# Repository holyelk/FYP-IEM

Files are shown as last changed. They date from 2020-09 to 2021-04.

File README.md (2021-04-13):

# FYP-IEM
Repository for Bryan's IEM FYP

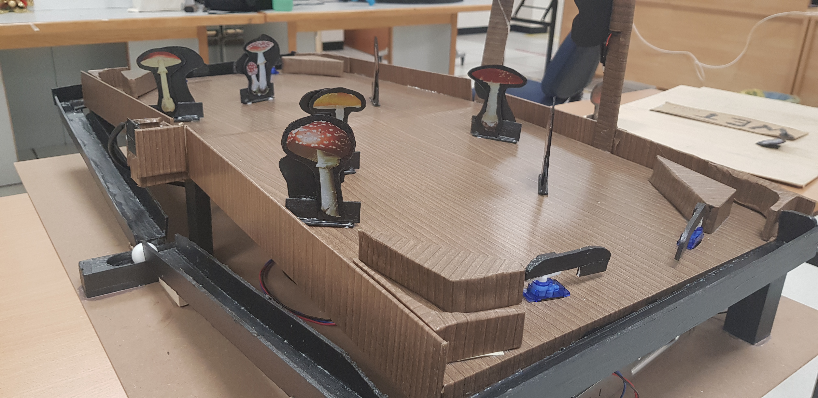
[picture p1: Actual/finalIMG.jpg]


***
### Top level folders will represent what is in them
- Actual
- Research

***
### Actual
Consists of the final code, circuit diagram and the archive of work in progress for this project

### Research
Consists of ideation, planning and other documents before the implementation

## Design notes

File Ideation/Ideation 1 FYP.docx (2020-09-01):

Ideation FYP:

Hiding ducks

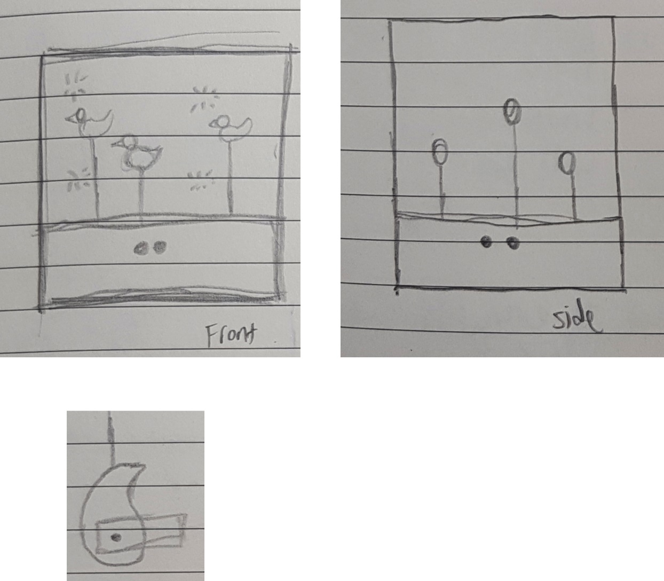
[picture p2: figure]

There will be a box with ducks inside which will be moving. Sensors will be attached to the box and if they sense anyone approaching from within a certain radius, the ducks will hide. This is achieved by making use of a certain shape (shown on the bottom left) to translate circular motion to vertical motion. Possible sensors to use for people sensing is an ultrasonic sensor or a RCWL-0516 Microwave proximity sensor.

The idea behind this is COVID19. As we have seen in the news, without people, nature has been returning to urban areas. Thus this is a replica of humans disappearing and animals returning.

Theremin concept

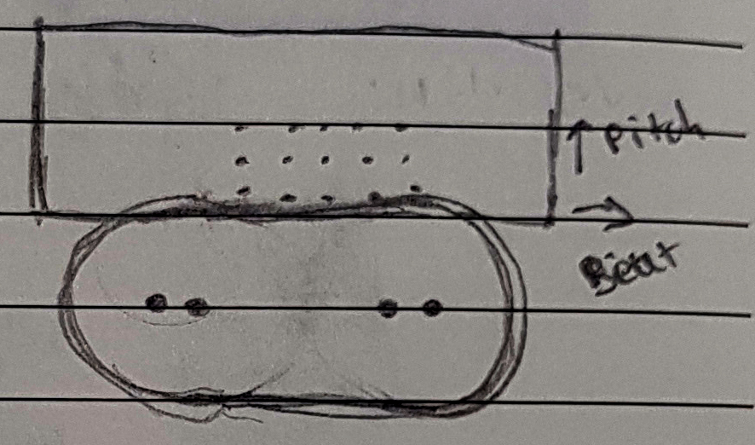
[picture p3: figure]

Using the concept of a theremin where distance and direction of the hand from the antenna is used to measure the pitch and beat of the instrument, I though of using 2 sensors to measure the distance from the display and play the appropriate pitch and beat. An alternative to using distance sensors would be using a camera and having certain poses correspond to some fixed beats/pitches. The beat and pitch would then be displayed on the LED matrix board on the back.

Interactive water display

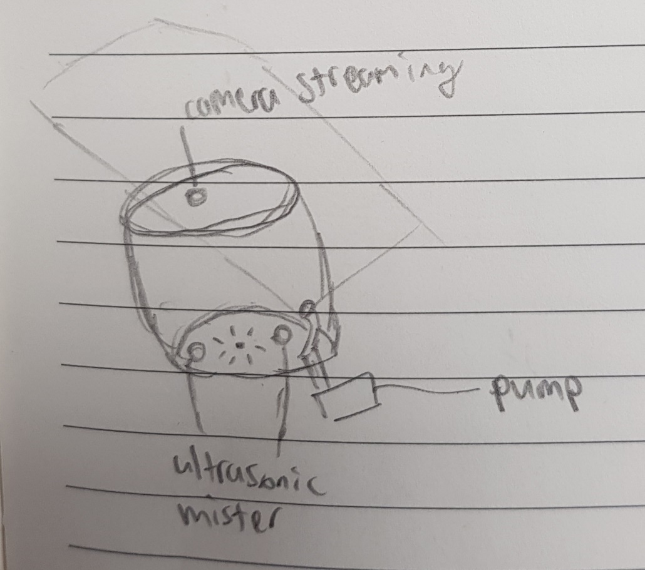
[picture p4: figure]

Through an application online, users will be able to see and interact with this water display. They will be able to see it through a camera the will be streaming from the top and control various actuators through the internet. Various actuators currently thought off are, LED lights, mini water pumps and ultrasonic misters. These 3 would already allow for a wide range of different displays in the water.

I understand that due to the water element, this might be a bit messy.

Real time weather display

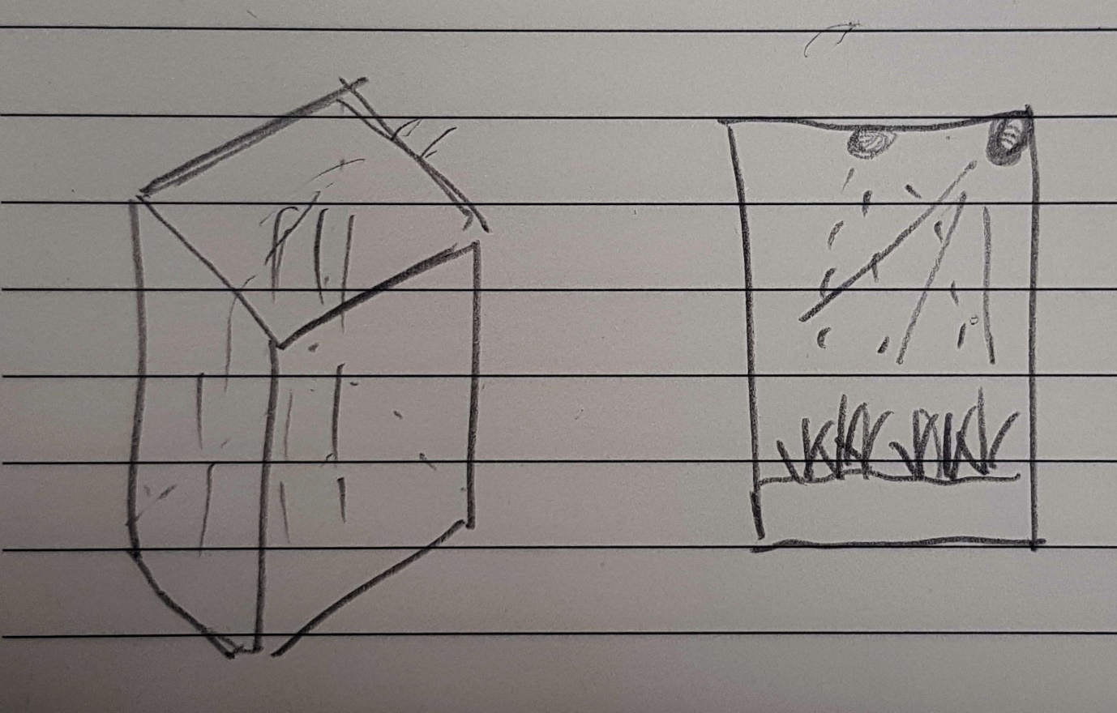
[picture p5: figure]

Using connections to the internet, a semi enclosed tank will replicate the weather we are having in real time. Light for the sun, water sprinkler/pump for rain. As Singapore has only 2 kinds of weather, perhaps temperature can be taken into account as well using a Peltier device.

An alternative would be to have the user control the kind of weather inside the tank via buttons or a webapp.

Magnetic Chaos

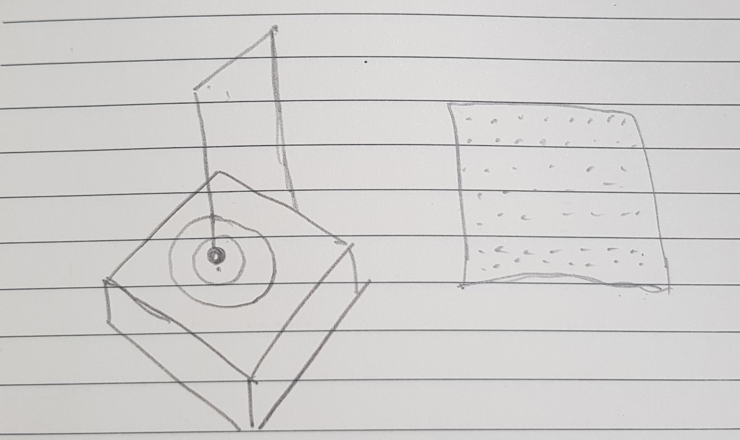
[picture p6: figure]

A magnet will be suspended above the board which is an LED matrix. Beneath the board are hall effect sensors able to sense the magnetic field created by the magnet. Upon a strong magnetic field, IE: The magnet is above the sensor, the corresponding led will light up. This will create a visualization of the chaos theory in action. The LEDs will also be replicated in the digital world by having a screen the represents the LEDs lighting up in real time.

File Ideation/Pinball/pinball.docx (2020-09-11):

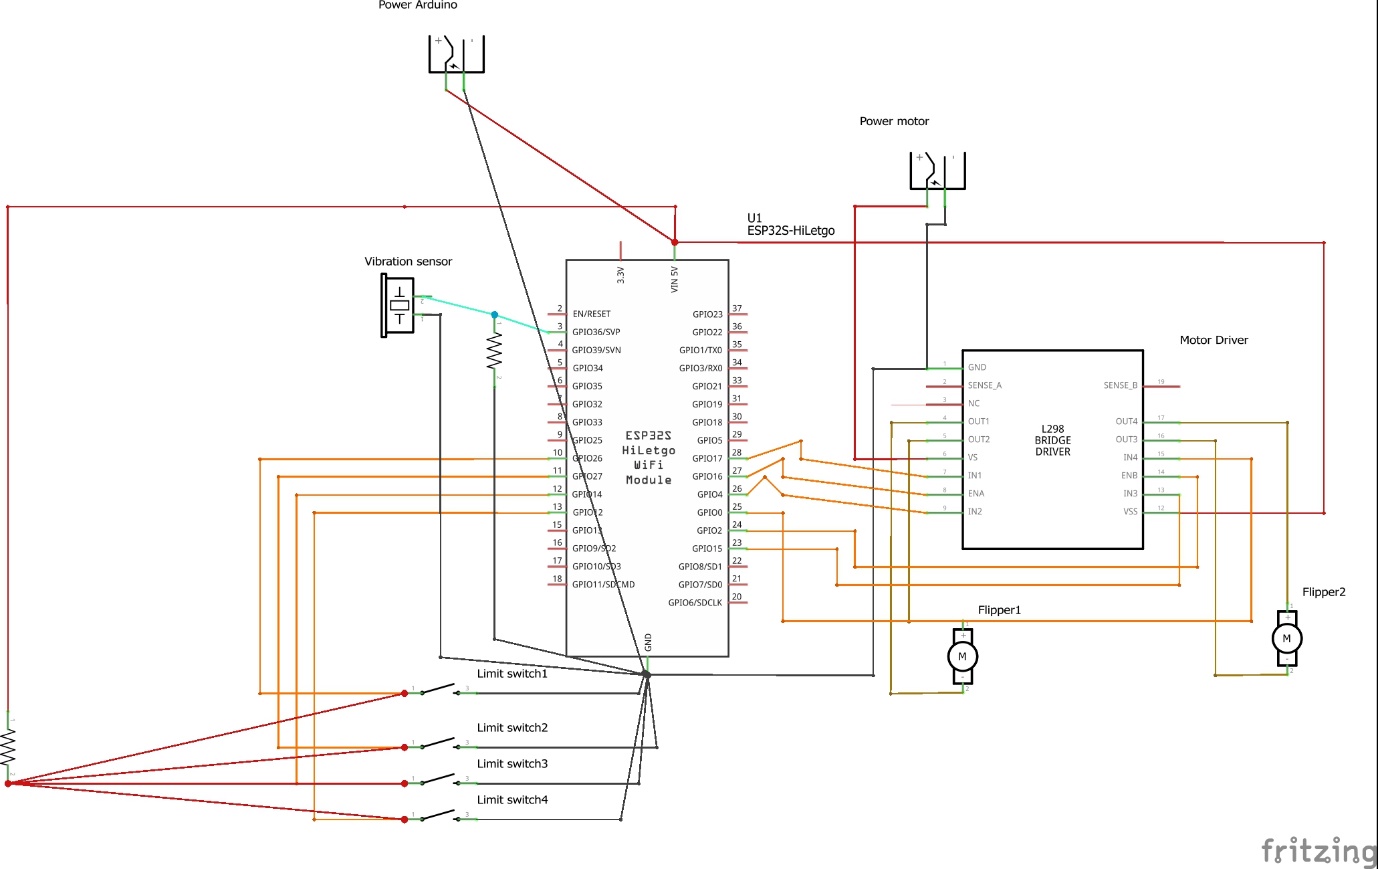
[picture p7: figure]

Parts required:

1x ESP32

2x Power source

2x DC Motors

1x L298 dual H-Bridge Motor Driver

8x Vibration sensors

4x Limit Switches

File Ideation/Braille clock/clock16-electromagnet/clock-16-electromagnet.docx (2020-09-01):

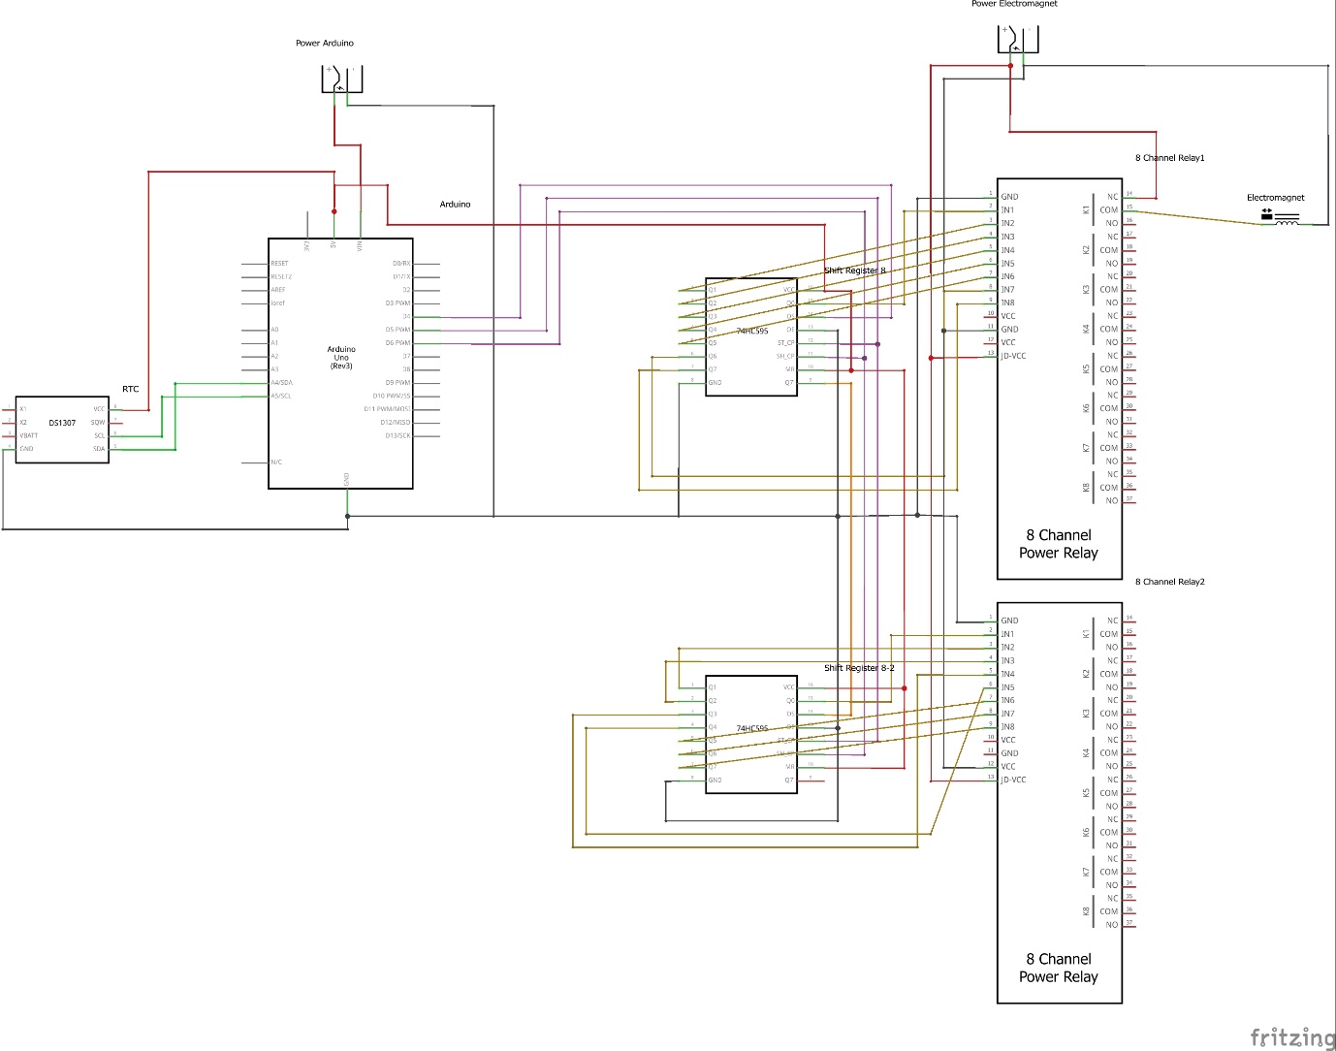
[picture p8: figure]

Parts required:

1x DS1307 (RTC module)

1x Arduino Uno

2x Power source

2x 74HC595 Shift register

2x 8 Channel Power Relay OR 1x 16 Channel Power Relay

16x 12v electromagnet

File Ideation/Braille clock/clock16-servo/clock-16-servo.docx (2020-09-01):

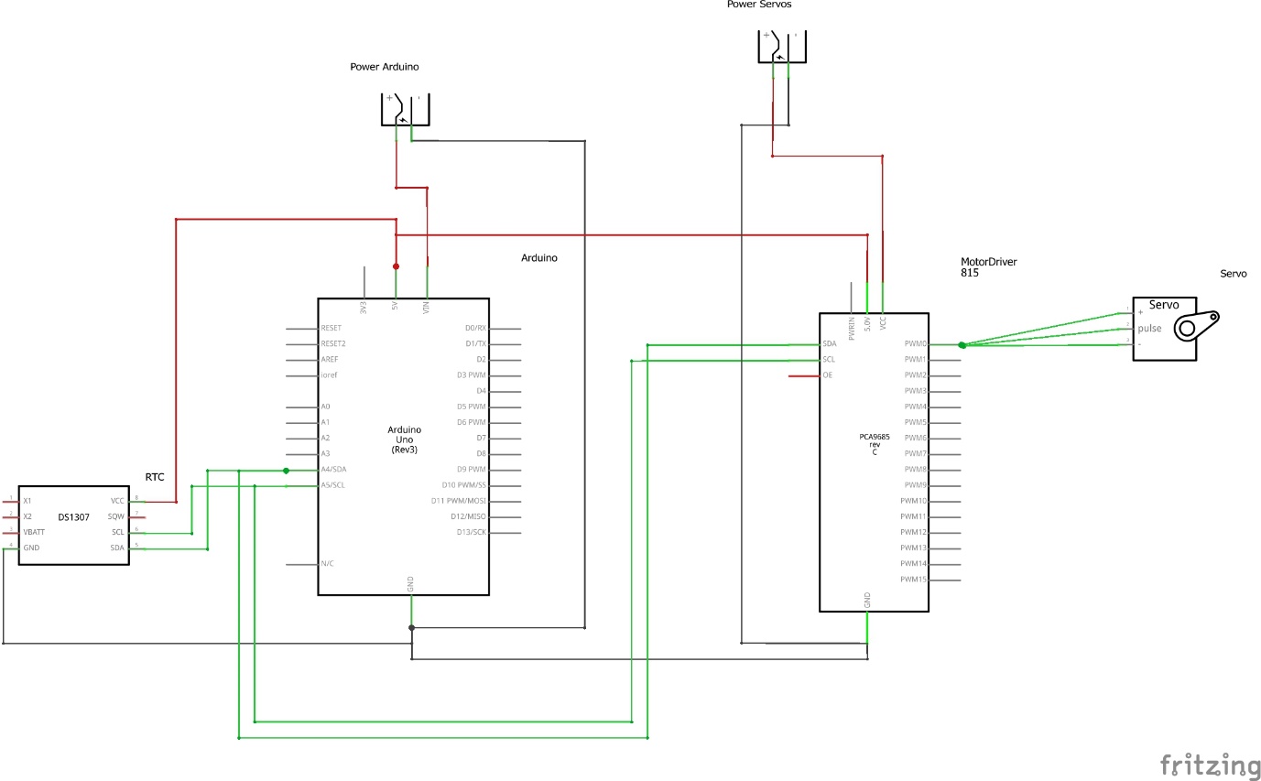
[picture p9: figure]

Parts required:

1x DS1307 (RTC module)

1x Arduino Uno

2x Power source

1x PCA9685 PWM Controller

16x Servos

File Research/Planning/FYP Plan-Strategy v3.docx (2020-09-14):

FYP Plan/Strategy

Background:

The objective of this project is to and construct creative interactive displays using Arduino/Raspberry Pi controller, sensors, actuators, LEDs and speaker, with light, sound, animation and wireless communications. In light of COVID-19 there should also be a virtual display done at the end to allow for a non-physical experience of the project.

The background would be to create an interactive display that is able to be showcased for IEM’s open house displays.

Ideation:

Taking inspiration from both Pong and Pinball, the idea is to create a pinball like game where the user plays against a computer-controlled board to attempt to score. One side will be controlled by the user and the other will be by the computer.

Being pinball like, the goal is defended by the use of 2 flippers and those flippers are used to attack as well. There will be static and dynamic obstacles on the board and in the way of the goals. To ensure users are able to score, the opponent will be programmed in such a way that allows it to sometime miss the ball coming towards it.

The brains of the project will be an Arduino board. The Arduino board will have 3 main functions. Keeping score, controlling the robot opponent and controlling the obstacles. Score will be kept by sensors at the end of the board if it detects the ball then it will add one point. Points will be shown by a 7-segment display. The Arduino will be using IR sensors to see if the ball is coming and use them to know when to activate the flippers. How the flippers will be made will have to be tested. 3 possible paths can be taken. Using a servo motor, using a DC motor with limit switches and using solenoids. Testing will need to be done to see which is sufficient. Lastly, there will be 2 kinds of obstacles. Static and dynamic. Static ones are just there but will have sensors to know if the ball has hit them. If it has been hit, it will light up. Dynamic obstacles are those that will move. These will either be moved by DC motors or servo motors. Having these dynamic obstacles will add more uncertainty and unpredictability to the ball making it more interesting.

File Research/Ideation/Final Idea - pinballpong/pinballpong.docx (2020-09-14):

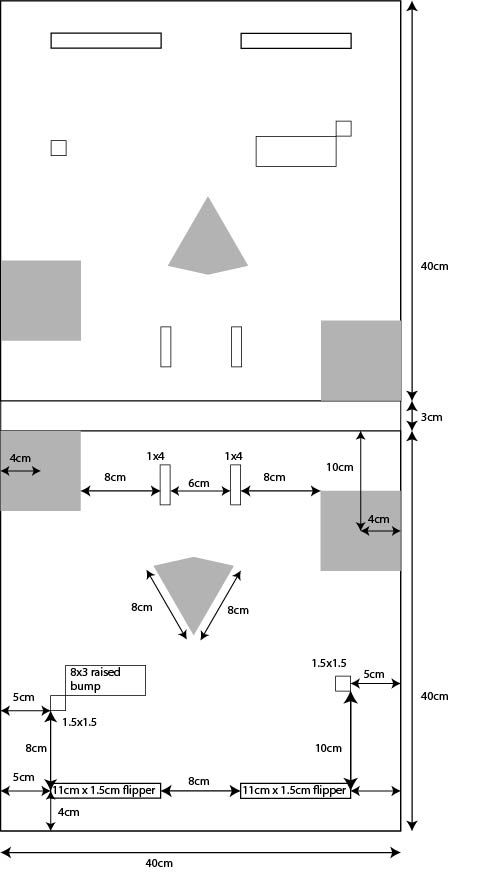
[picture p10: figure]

Figure 1

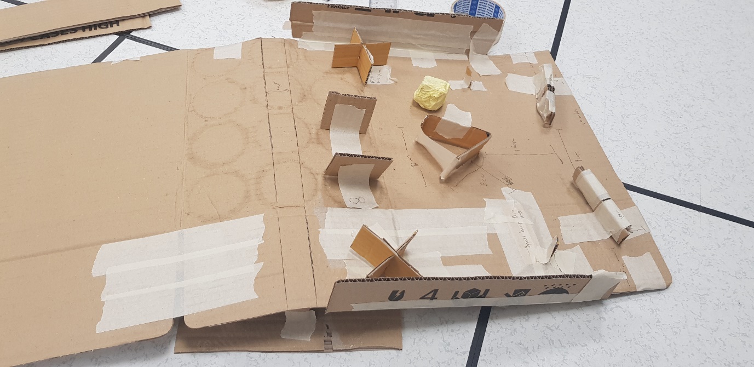
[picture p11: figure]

Figure 2

The entire board will be in the shape of an A-frame slightly tilted toward each side and flat in the middle to allow the ball to roll down on each respective side. The highest point of elevation of the flat middle is 5cm. This allows for a 7-degree incline which is just nice to prevent the ball from rolling too fast. Depending on the ball size selected, the obstacles are subject to change. The current design uses a ping pong ball of standard diameter 4cm as the ball size.

As obstacles are subject to change based on selection of ball, first order of business will be to select the ball and hence determine which type of flippers are strong enough.

Flippers:

If servo:

1x PCA9685 driver ($3)

4x servos ($3 each)

Total - $15

If DC Motor:

2x L298N driver ($2.50 each)

8x Limit Switch ($2.50 for 10)

4x DC Motor ($2 each)

Total - $15.50

If Solenoid:

2x 2N2222A Transistor ($0.50 each)

4x Solenoid ($4 each)

Total - $17

As we can initially see, the best option would be the servo as it is the cheapest. However, the push strength of the servo may not be enough and tests will need to be carried out.

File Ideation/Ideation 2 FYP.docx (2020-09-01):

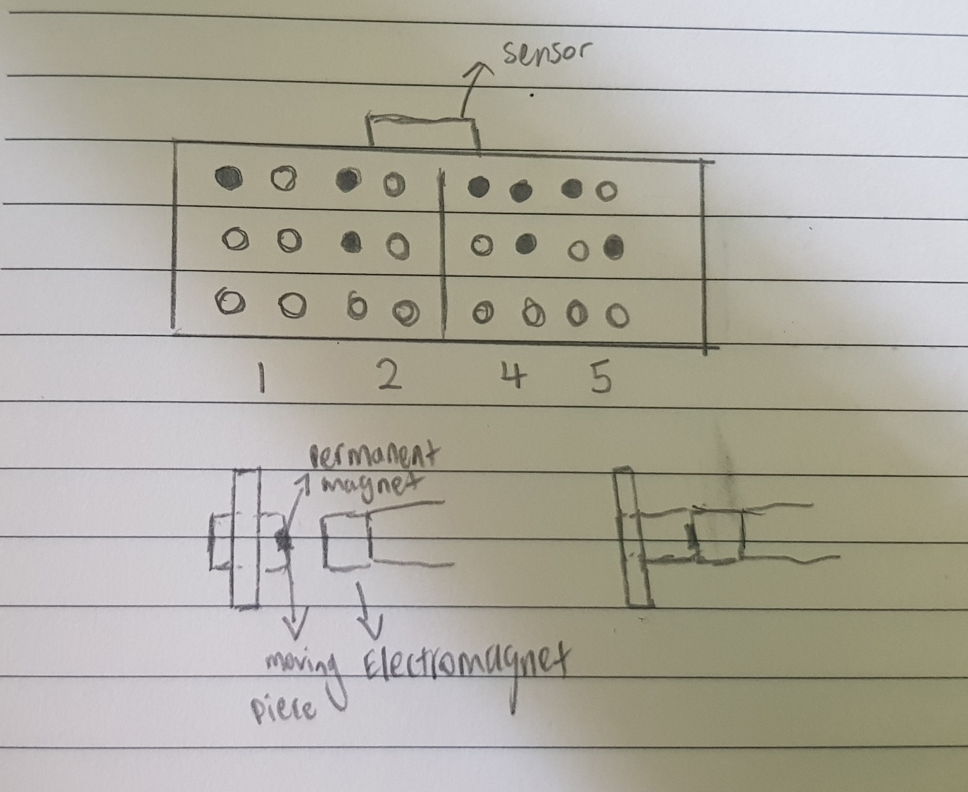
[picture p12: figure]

A braille clock for the visually impaired. How it will work is that there are 24 movable blocks representing the braille numbers. These will move in or out based on the corresponding time. The movement is controlled by an electromagnet that activates and repels based on the correct braille conversion given for the time.

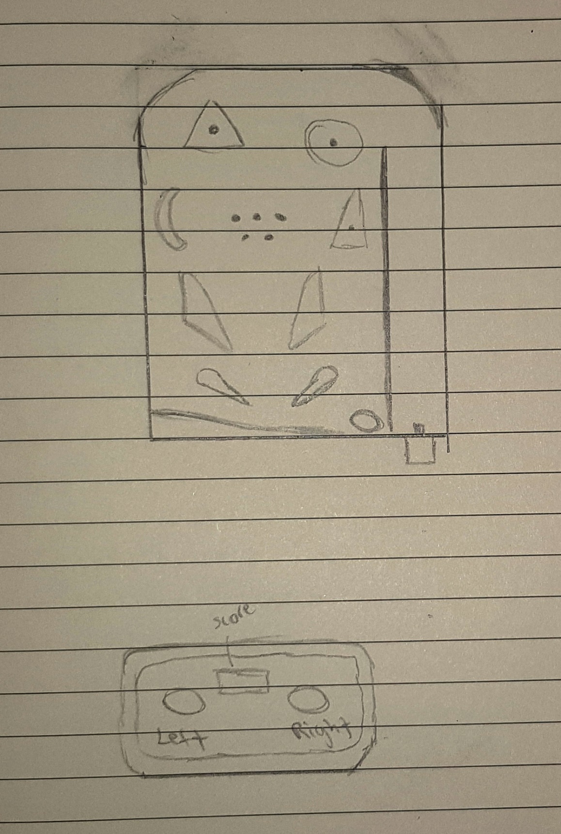
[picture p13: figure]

An IoT Pinball machine. The pinball machine itself is physical. However, the controls are controlled by a smartphone connected to an ESP32 microcontroller.

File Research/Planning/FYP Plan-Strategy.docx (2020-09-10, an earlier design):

FYP Plan/Strategy

Background:

The objective of this project is to and construct creative interactive displays using Arduino/Raspberry Pi controller, sensors, actuators, LEDs and speaker, with light, sound, animation and wireless communications. In light of COVID-19 there should also be a virtual display done at the end to allow for a non-physical experience of the project.

The background would be to create an interactive display that is able to be showcased for IEM’s open house displays.

Ideations:

There are 2 ways that are possible for exploration. The first is an interactive display which depends on light and sound coupled with sensors for activation to create an interactive display. The other would be a tactile interactive display where rather than using light and sound, it uses touch and sound to interact with the audience.

An idea for the first point is to create an IoT pinball machine where the pinball board is physical but the controls are through the user’s mobile phone. This is a bonus during the COVID-19 period as people would not be physically touching the device and only their mobile phones which they already have contact with. If this were to proceed, research would have to be done on the various IoT boards available. Ranging from a Raspberry Pi to a ESP32 controller. Following that, testing and research will be done for how to display the controls on the phone which will have a connection to the various actuators on the pinball machine. Lastly would be the testing of the components and the actual implementation of the device.

An idea for the second point would be since it is to be tactile and sound interaction, the best group of people to cater this towards would be the visually impaired people. The initial idea is to have a clock with numbers represented in braille which would be represented by moving dots. However, further research and interviews would have to be done with visually impaired persons to deem if this idea should move forward. To that end, I have contacted Singapore Association for the Visually Handicapped (SAVH) to seek their advice on this matter. The outcome of this would determine if the FYP would be the IoT pinball machine or the Braille clock.

Refer to TimeSchedule.xlsx for the time schedule

Update 10/9/2020:

A few emails between myself and SAVH and I was given insight into what the visually handicapped people are actually using. I was informed that they currently have 3 kinds of time telling devices being used. The first one that tells the time through sound, the second is through touch of the numbers on a clock face and the last is a braille watch. Since there already exists a braille watch, there is no point in re-inventing the wheel and I will not proceed further on this topic. This means that my focus is now on the IoT pinball machine.

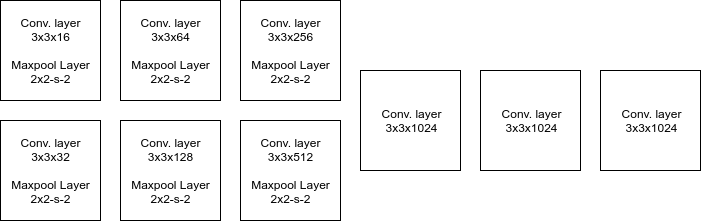
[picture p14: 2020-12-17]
Research/Tinyyolo_architecture.png

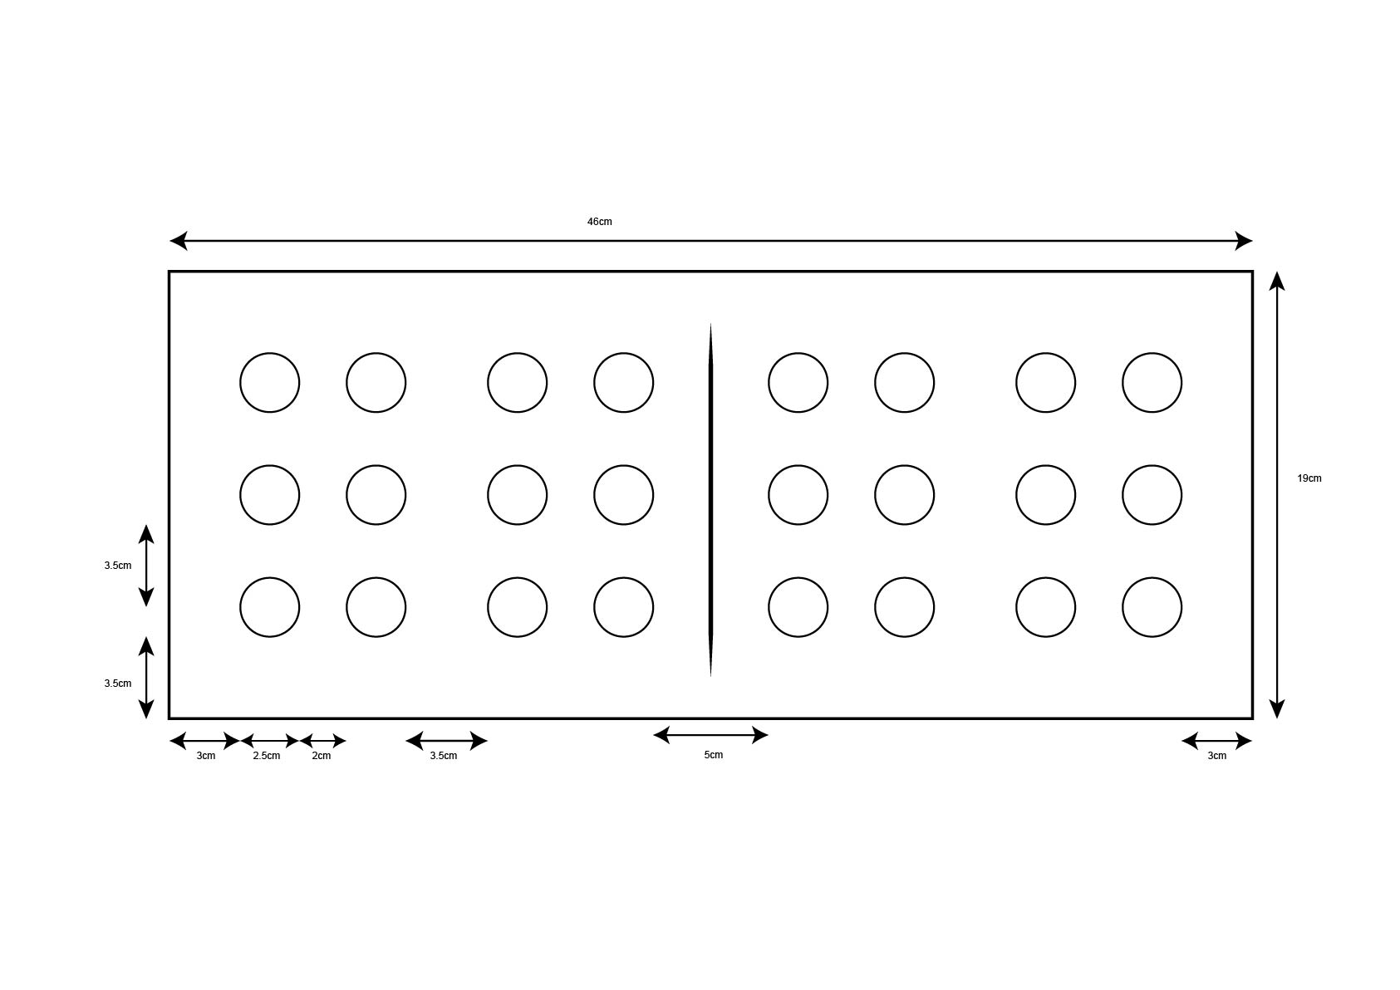
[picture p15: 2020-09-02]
Ideation/Braille clock/Diagram to scale-clock16-01.jpg

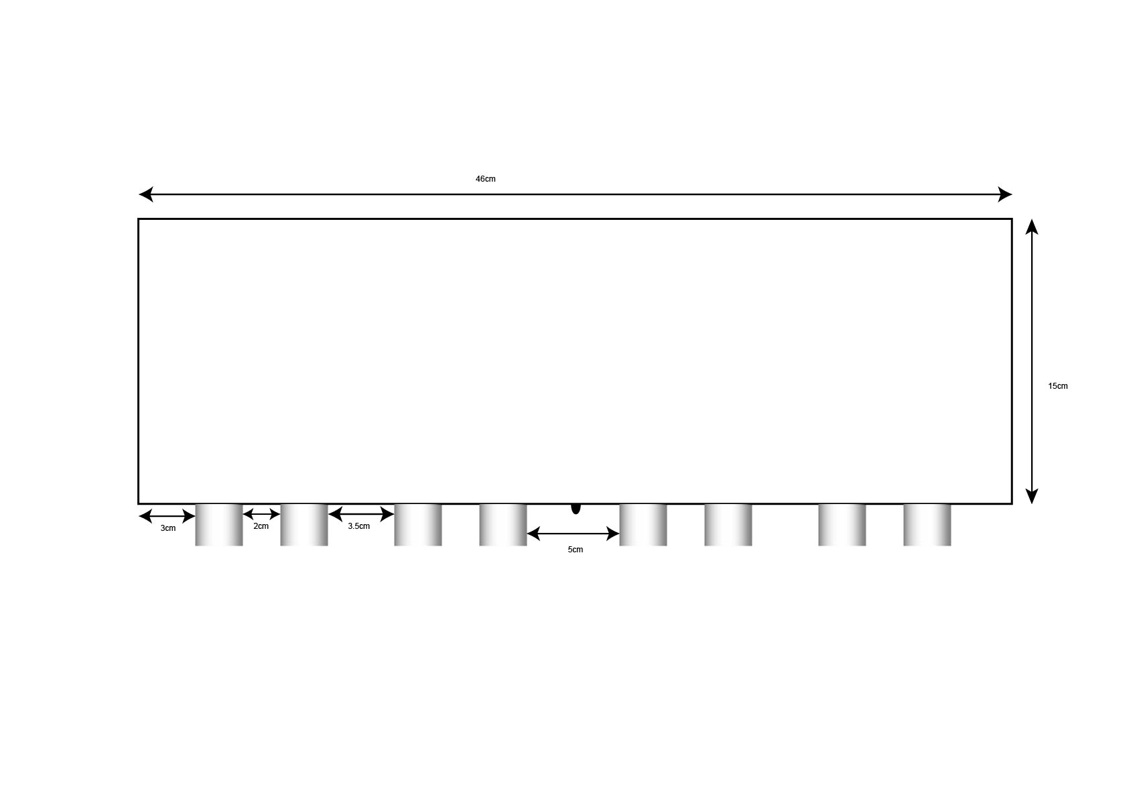
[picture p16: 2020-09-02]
Ideation/Braille clock/Diagram to scale-clock16-02.jpg

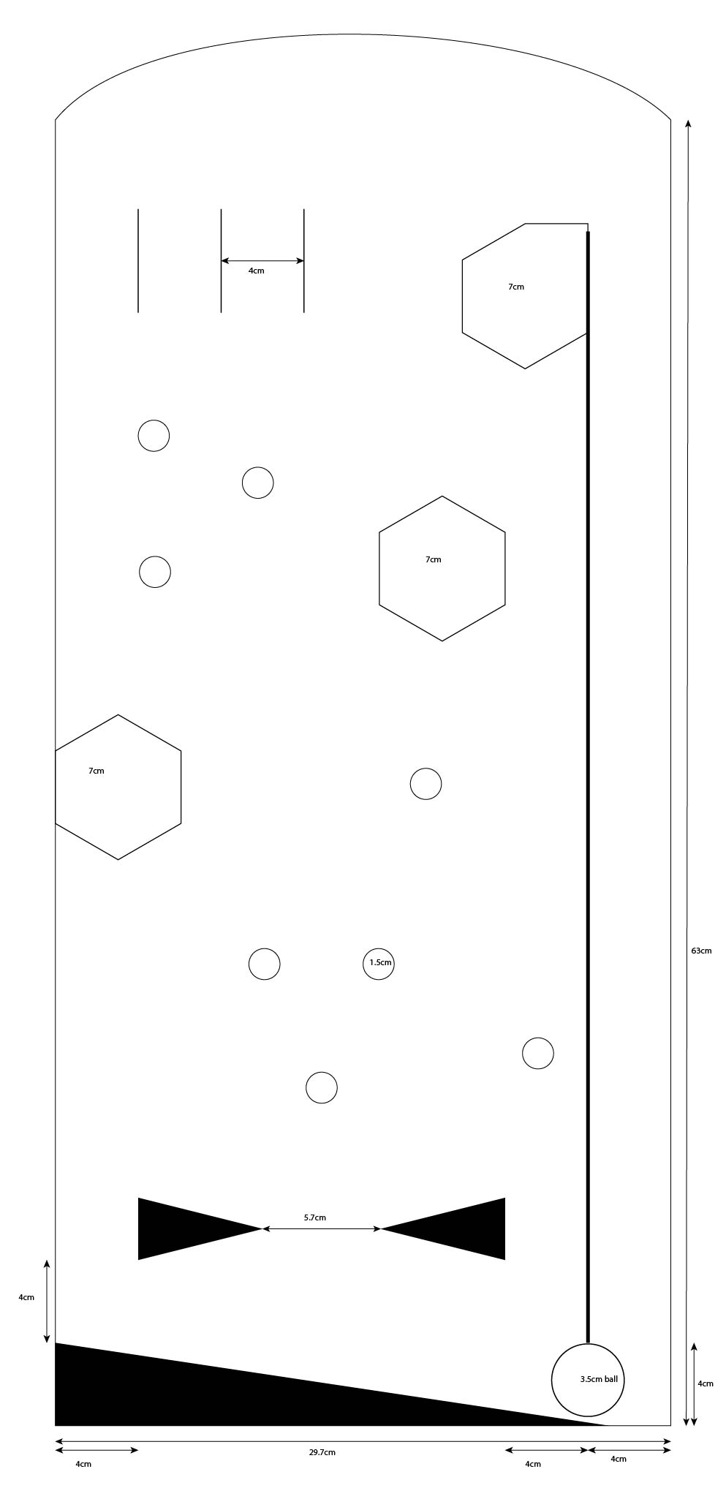
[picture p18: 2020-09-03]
Ideation/Pinball/Diagram to scale-pinball-01.jpg

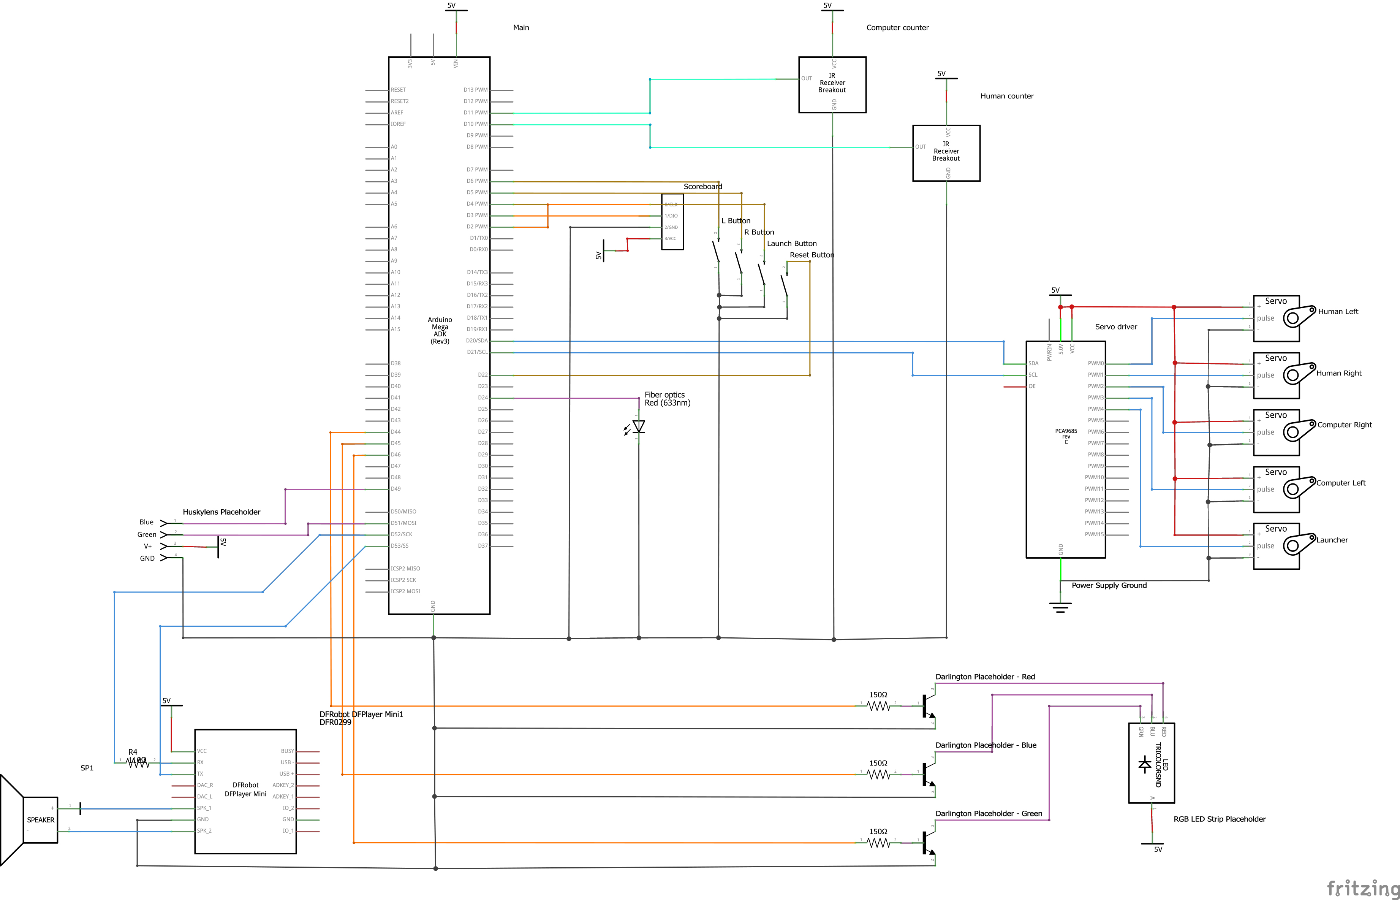
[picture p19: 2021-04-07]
Actual/circuitdiagram_actual_schem.jpg

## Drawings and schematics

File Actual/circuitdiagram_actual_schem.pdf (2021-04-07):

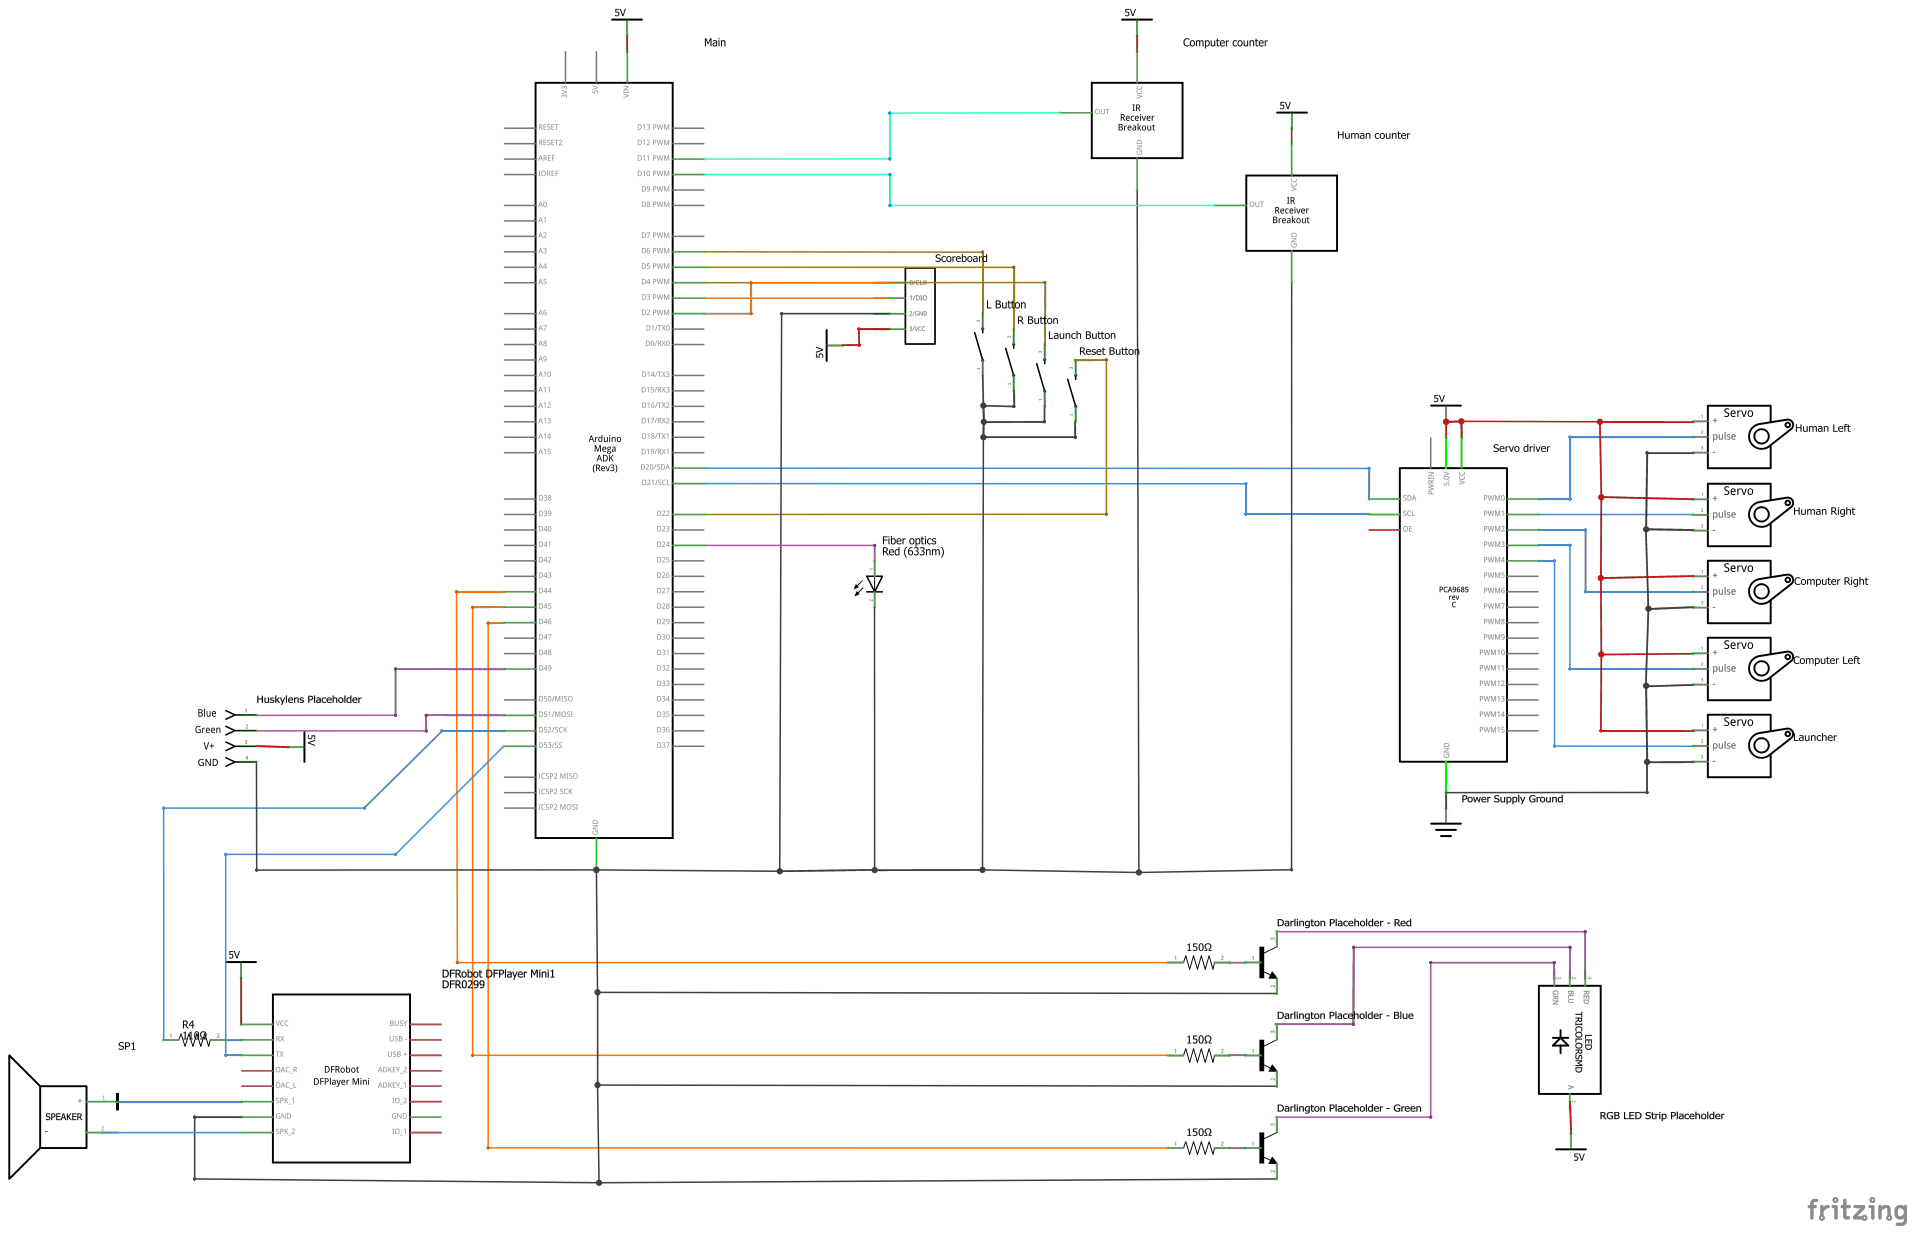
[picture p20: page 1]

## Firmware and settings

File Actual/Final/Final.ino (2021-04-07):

//Libraries import
#include <Wire.h>
//PCA9685 Library
#include <Adafruit_PWMServoDriver.h>
// 7 segment Library
#include <TM1637Display.h>
//HuskyLens library
#include "HUSKYLENS.h"
#include "SoftwareSerial.h"
//Debounce library
#include <Button.h>
//DFplayer library
#include "DFRobotDFPlayerMini.h"
//non blocking Delay library
#include <avdweb_VirtualDelay.h>

//PINOUTS
//PCA9685 pinout VCC->5V, GND->GND, SDA->SDA, SCL->SCL
//L/R Button pinout 6 & 5
//Launch button pinout 4
//Reset score button pinout 22
//7 Segment pinout CLK->2 & DIO->3
//Score counter pinout human_counter->10 & com_counter->11
//HUSKYLENS green line >> Pin 51; blue line >> Pin 49
//DFPlayer pinout 26 & 28

// called this way, it uses the default address 0x40
Adafruit_PWMServoDriver pwm = Adafruit_PWMServoDriver();

#define SERVOMIN  100 // This is the 'minimum' pulse length count (out of 4096)
#define SERVOMAX  560 // This is th' pulse length count (out of 4096)
#define USMIN  600 // This is the rounded 'minimum' microsecond length based on the minimum pulse of 150
#define USMAX  2400 // This is the rounded 'maximum' microsecond length based on the maximum pulse of 600
#define SERVO_FREQ 50 // Anale 'maximumog servos run at ~50 Hz updates

//7 segment
#define CLK 2
#define DIO 3
TM1637Display display(CLK, DIO);

//Score counter sensor
#define human_counter 10
#define com_counter 11

//fiber
#define fiber1 24

//RGB strip
#define REDPIN 44
#define GREENPIN 46
#define BLUEPIN 45
int rgbStripRand;
int rStrip,gStrip,bStrip;

//Huskylens
HUSKYLENS huskylens;
SoftwareSerial mySerial(51, 49); // RX, TX
void printResult(HUSKYLENSResult result);

//DFplayer
SoftwareSerial mySoftwareSerial(53, 52); // RX, TX
DFRobotDFPlayerMini myDFPlayer;

//PCA9685 servo numbers
uint8_t servonum[] = {0, 1, 4, 2, 3};
//Pulse length for servo angle
uint16_t pulselength;

//Left and Right flipper button
int inPin[] = {5, 6};   // choose the input pin (for a pushbutton) for servonum
int buttonVal[] = {0, 0};     // variable for reading the pin status
int numOfButtons = 2;

//Debounce for launch and reset button
Button buttonLaunch(4); // Connect your button between pin 4 and GND
Button buttonReset(22); // Connect your button between pin 22 and GND


//7 Segment user and com scores
int user_score = 0;
int com_score = 0;

//random number for computer flipper to ensure ball does not get stuck
int randNumber;

//Non blocking delay to allow for ball launcher to reset
VirtualDelay singleDelay;

//LED Strip fading effect
// define directions for LED fade
#define UP 0
#define DOWN 1
// constants for min and max PWM
const int minPWM = 0;
const int maxPWM = 255;
 // State Variable for Fade Direction
byte fadeDirection = UP;
// Global Fade Value
// but be bigger than byte and signed, for rollover
int fadeValue = 0;
// How smooth to fade?
byte fadeIncrement = 5;
// millis() timing Variable, just for fading
unsigned long previousFadeMillis;
// How fast to increment?
int fadeInterval = 50;


void setup() {

  pwm.begin();
  pwm.setOscillatorFrequency(27000000);
  pwm.setPWMFreq(SERVO_FREQ);  // Analog servos run at ~50 Hz updates

  //initialize huskylens serial protocol
  Serial.begin(9600);
  mySerial.begin(9600);
  while (!huskylens.begin(mySerial))
  {};

  //initialize DFplayer
  mySoftwareSerial.begin(9600);

  if (!myDFPlayer.begin(mySoftwareSerial)) {
    
  }
  myDFPlayer.volume(10);  //Set volume value. From 0 to 30
  myDFPlayer.loop(1);  //Play the first mp3
  mySerial.listen();

  //Initialize 7 Segment
  uint8_t data[] = { 0xff, 0xff, 0xff, 0xff };
  uint8_t blank[] = { 0x00, 0x00, 0x00, 0x00 };
  display.setBrightness(4, true);
  display.clear();

  //initialize buttons and internal resistor. One side to ground. other to pin
  pinMode(inPin[0], INPUT);
  digitalWrite(inPin[0], HIGH);
  pinMode(inPin[1], INPUT);
  digitalWrite(inPin[1], HIGH);
  pinMode(inPin[2], INPUT);
  digitalWrite(inPin[2], HIGH);

  //initialize score counter pins
  pinMode(10, INPUT);
  pinMode(11, INPUT);

  //initialize fiber
  pinMode(fiber1, OUTPUT);
  //digitalWrite(fiber1, LOW);

  //initialize rgb strip
  pinMode(REDPIN, OUTPUT);
  pinMode(GREENPIN, OUTPUT);
  pinMode(BLUEPIN, OUTPUT);

  //Initialize debounce
  buttonLaunch.begin();
  buttonReset.begin();

  //Set score to be 0:0
  refreshScore();

  delay(10);
}

void loop() {

  unsigned long currentMillis = millis();
  //RGB LED
  ledFader(currentMillis);

  //loop through all buttons to see if pressed
  for (int thisButton = 0; thisButton < numOfButtons; thisButton++) {
    buttonVal[thisButton] = digitalRead(inPin[thisButton]);  // read input value

    switch (thisButton) {
      case 0:
        if (buttonVal[thisButton] == LOW) {  //LOW is button pressed
          pulselength = map(150, 0, 180, SERVOMIN, SERVOMAX);
          pwm.setPWM(servonum[thisButton], 0, pulselength);
        } else {
          pulselength = map(90, 0, 180, SERVOMIN, SERVOMAX);
          pwm.setPWM(servonum[thisButton], 0, pulselength);
        }
        break;

      case 1:
        if (buttonVal[thisButton] == LOW) {  //LOW is button pressed
          pulselength = map(20, 0, 180, SERVOMIN, SERVOMAX);
          pwm.setPWM(servonum[thisButton], 0, pulselength);
        } else {
          pulselength = map(80, 0, 180, SERVOMIN, SERVOMAX);
          pwm.setPWM(servonum[thisButton], 0, pulselength);
        }
        break;

    }
  }

  if (buttonLaunch.pressed()) {
    //Serial.println("Button 1 pressed");
    launchBall();
  }

  if (buttonReset.pressed()) {
    //Serial.println("Button 1 pressed");
    resetScore();
  }

  scoreCounter();

  if (!huskylens.request()) Serial.println(F("Fail to request data from HUSKYLENS, recheck the connection!"));

  else
  {
    while (huskylens.available())
    {
      HUSKYLENSResult result = huskylens.read();
      printResult(result);
    }
  }


  if (singleDelay.elapsed()) {
    pulselength = map(142, 0, 180, SERVOMIN, SERVOMAX);
    pwm.setPWM(servonum[2], 0, pulselength);
  }




}

void launchBall() {


  //148,90
  //for(int degreeVal = 148; degreeVal > 90; degreeVal--){
  pulselength = map(90, 0, 180, SERVOMIN, SERVOMAX);
  pwm.setPWM(servonum[2], 0, pulselength);
  singleDelay.start(1000);
  //Serial.println("degreeVal");


  //}

}

void refreshScore() {
  //Function to refresh the scoreboard
  display.showNumberDecEx(com_score, 0, false, 2, 2);
  display.showNumberDecEx(user_score, 0b01000000, false, 2, 0);
  //mySerial.listen();
}

void scoreCounter() {
  
  if (digitalRead(com_counter) == LOW) {
    user_score++;
    refreshScore();
    myDFPlayer.play(2);
    analogWrite(GREENPIN, 0);
    digitalWrite(fiber1, HIGH);
    bStrip = 255;
    analogWrite(BLUEPIN, bStrip);
    delay(1000);
    digitalWrite(fiber1, LOW);
    bStrip = 0;
    analogWrite(BLUEPIN, bStrip);
    myDFPlayer.loop(1);
  }
  if (digitalRead(human_counter) == LOW) {
    com_score++;
    refreshScore();
    myDFPlayer.play(2);
    analogWrite(GREENPIN, 0);
    digitalWrite(fiber1, HIGH);
    rStrip = 255;
    analogWrite(REDPIN, rStrip);
    delay(1000);
    digitalWrite(fiber1, LOW);
    rStrip = 0;
    analogWrite(REDPIN, rStrip);
    myDFPlayer.loop(1);
  }

}

void resetScore() {
  user_score = 0;
  com_score = 0;
  refreshScore();
  myDFPlayer.stop();
  myDFPlayer.loop(1);
  delay(500);
}

void printResult(HUSKYLENSResult result) {
  int posX, posY;
  if (result.command == COMMAND_RETURN_BLOCK) {
    posX = result.xCenter;
    posY = result.yCenter;

    if ((posX <= 160) && (posX >= 40) && (posY >= 120) && (posY <= 240)) {
      comRFlipper();
    }

    if ((posX <= 160) && (posX >= 40) && (posY >= 0) && (posY <= 120)) {
      comLFlipper();
    }


    pulselength = map(90, 0, 180, SERVOMIN, SERVOMAX);
    pwm.setPWM(servonum[3], 0, pulselength);
    pulselength = map(80, 0, 180, SERVOMIN, SERVOMAX);
    pwm.setPWM(servonum[4], 0, pulselength);
  }

  else {
    Serial.println("Object unknown!");
  }
}

void comRFlipper() {
  randNumber = random(0, 50);
  delay(randNumber);
  pulselength = map(90, 0, 180, SERVOMIN, SERVOMAX);
  pwm.setPWM(servonum[3], 0, pulselength);
  randNumber = random(150, 350);
  delay(randNumber);
  pulselength = map(30, 0, 180, SERVOMIN, SERVOMAX);
  pwm.setPWM(servonum[3], 0, pulselength);
  delay(200);
}

void comLFlipper() {
  randNumber = random(0, 50);
  delay(randNumber);
  pulselength = map(80, 0, 180, SERVOMIN, SERVOMAX);
  pwm.setPWM(servonum[4], 0, pulselength);
  randNumber = random(150, 350);
  delay(randNumber);
  pulselength = map(140, 0, 180, SERVOMIN, SERVOMAX);
  pwm.setPWM(servonum[4], 0, pulselength);
  delay(200);
}

void ledFader(unsigned long thisMillis) {
  // is it time to update yet?
  // if not, nothing happens
  if (thisMillis - previousFadeMillis >= fadeInterval) {
    // yup, it's time!
    if (fadeDirection == UP) {
      fadeValue = fadeValue + fadeIncrement;  
      if (fadeValue >= maxPWM) {
        // At max, limit and change direction
        fadeValue = maxPWM;
        fadeDirection = DOWN;
      }
    } else {
      //if we aren't going up, we're going down
      fadeValue = fadeValue - fadeIncrement;
      if (fadeValue <= minPWM) {
        // At min, limit and change direction
        fadeValue = minPWM;
        fadeDirection = UP;
      }
    }
    //rgbStripRand = random(44, 47);
    // Only need to update when it changes
    analogWrite(GREENPIN, fadeValue);
    //analogWrite(REDPIN, fadeValue);   
 
    // reset millis for the next iteration (fade timer only)
    previousFadeMillis = thisMillis;
  }
}

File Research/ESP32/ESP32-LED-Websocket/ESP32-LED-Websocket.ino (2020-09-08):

#include <WiFi.h>
#include <SPIFFS.h>
#include <ESPAsyncWebServer.h>
#include <WebSocketsServer.h>

// Constants
const char *ssid = "ESP32-AP";
const char *password =  "password";
const char *msg_toggle_led = "toggleLED";
const char *msg_get_led = "getLEDState";
const int dns_port = 53;
const int http_port = 80;
const int ws_port = 1337;
const int led_pin = 15;

// Globals
AsyncWebServer server(80);
WebSocketsServer webSocket = WebSocketsServer(1337);
char msg_buf[10];
int led_state = 0;

/***********************************************************
 * Functions
 */

// Callback: receiving any WebSocket message
void onWebSocketEvent(uint8_t client_num,
                      WStype_t type,
                      uint8_t * payload,
                      size_t length) {

  // Figure out the type of WebSocket event
  switch(type) {

    // Client has disconnected
    case WStype_DISCONNECTED:
      Serial.printf("[%u] Disconnected!\n", client_num);
      break;

    // New client has connected
    case WStype_CONNECTED:
      {
        IPAddress ip = webSocket.remoteIP(client_num);
        Serial.printf("[%u] Connection from ", client_num);
        Serial.println(ip.toString());
      }
      break;

    // Handle text messages from client
    case WStype_TEXT:

      // Print out raw message
      Serial.printf("[%u] Received text: %s\n", client_num, payload);

      // Toggle LED
      if ( strcmp((char *)payload, "toggleLED") == 0 ) {
        led_state = led_state ? 0 : 1;
        Serial.printf("Toggling LED to %u\n", led_state);
        digitalWrite(led_pin, led_state);

      // Report the state of the LED
      } else if ( strcmp((char *)payload, "getLEDState") == 0 ) {
        sprintf(msg_buf, "%d", led_state);
        Serial.printf("Sending to [%u]: %s\n", client_num, msg_buf);
        webSocket.sendTXT(client_num, msg_buf);

      // Message not recognized
      } else {
        Serial.println("[%u] Message not recognized");
      }
      break;

    // For everything else: do nothing
    case WStype_BIN:
    case WStype_ERROR:
    case WStype_FRAGMENT_TEXT_START:
    case WStype_FRAGMENT_BIN_START:
    case WStype_FRAGMENT:
    case WStype_FRAGMENT_FIN:
    default:
      break;
  }
}

// Callback: send homepage
void onIndexRequest(AsyncWebServerRequest *request) {
  IPAddress remote_ip = request->client()->remoteIP();
  Serial.println("[" + remote_ip.toString() +
                  "] HTTP GET request of " + request->url());
  request->send(SPIFFS, "/index.html", "text/html");
}

// Callback: send style sheet
void onCSSRequest(AsyncWebServerRequest *request) {
  IPAddress remote_ip = request->client()->remoteIP();
  Serial.println("[" + remote_ip.toString() +
                  "] HTTP GET request of " + request->url());
  request->send(SPIFFS, "/style.css", "text/css");
}

// Callback: send 404 if requested file does not exist
void onPageNotFound(AsyncWebServerRequest *request) {
  IPAddress remote_ip = request->client()->remoteIP();
  Serial.println("[" + remote_ip.toString() +
                  "] HTTP GET request of " + request->url());
  request->send(404, "text/plain", "Not found");
}

/***********************************************************
 * Main
 */

void setup() {
  // Init LED and turn off
  pinMode(led_pin, OUTPUT);
  digitalWrite(led_pin, LOW);

  // Start Serial port
  Serial.begin(115200);

  // Make sure we can read the file system
  if( !SPIFFS.begin()){
    Serial.println("Error mounting SPIFFS");
    while(1);
  }

  // Start access point
  WiFi.softAP(ssid, password);

  // Print our IP address
  Serial.println();
  Serial.println("AP running");
  Serial.print("My IP address: ");
  Serial.println(WiFi.softAPIP());

  // On HTTP request for root, provide index.html file
  server.on("/", HTTP_GET, onIndexRequest);

  // On HTTP request for style sheet, provide style.css
  server.on("/style.css", HTTP_GET, onCSSRequest);

  // Handle requests for pages that do not exist
  server.onNotFound(onPageNotFound);

  // Start web server
  server.begin();

  // Start WebSocket server and assign callback
  webSocket.begin();
  webSocket.onEvent(onWebSocketEvent);
  
}

void loop() {
  
  // Look for and handle WebSocket data
  webSocket.loop();
}

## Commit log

2020-09-01 Addition of schematics and parts
    [clock-16-output-servo.fzz, clock-16-output.fzz]
2020-09-02 Uploaded Pinball ideation
    [pinball.fzz]
2020-09-07 Create and added plan/time schedule
    [TimeSchedule.xlsx]
2020-09-08 Created ESP32 demo
2020-09-10 Update of Logbook and Time Schedule
    [TimeSchedule.xlsx]
2020-09-14 Update of file organization
    [clock-16-output-servo.fzz, clock-16-output.fzz, pinball.fzz]
2020-09-17 Added code for 1 flipper with button
    [1_flipper.ino]
2020-09-17 Added TM1637 Led driver for 4 digit 7 segment
2020-09-21 Update circuit diagram
    [circuitdiagram.fzz]
2020-10-28 Created actual arduino file
2021-04-07 Final Update
    [TimeSchedule.xlsx, circuitdiagram.fzz, circuitdiagram_actual.fzz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]
